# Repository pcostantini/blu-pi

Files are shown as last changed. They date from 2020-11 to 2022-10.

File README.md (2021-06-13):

# BLU-PI CYCLING COMPUTER

GPS Cycling Computer |  Raspberry Pi + GPS + ATTiny Odometer | Node.JS

| Overview | Intervals | Sys. Averages | Map | Menu | 
| --- | --- | --- | --- | ---- |
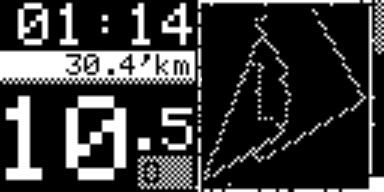
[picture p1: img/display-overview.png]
Overview Display
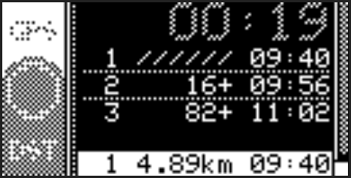
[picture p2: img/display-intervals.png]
Intervals Display
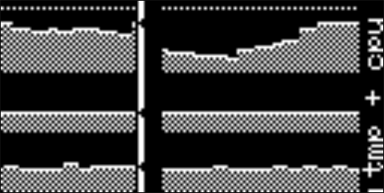
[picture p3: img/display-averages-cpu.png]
Sys. Averages Display
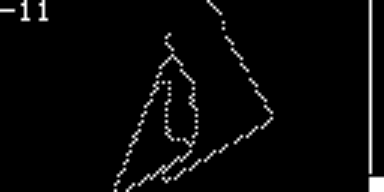
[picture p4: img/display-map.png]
Map Display
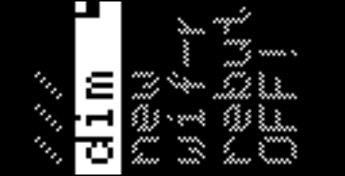
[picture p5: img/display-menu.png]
Menu Display
|  |  |  |  |  |

| Setup | Cockpit | Prototype |
| ----- | --- | --- |
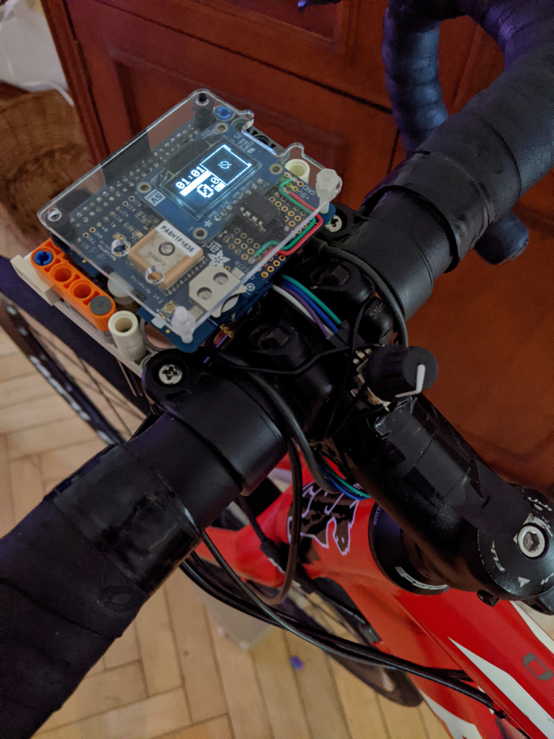
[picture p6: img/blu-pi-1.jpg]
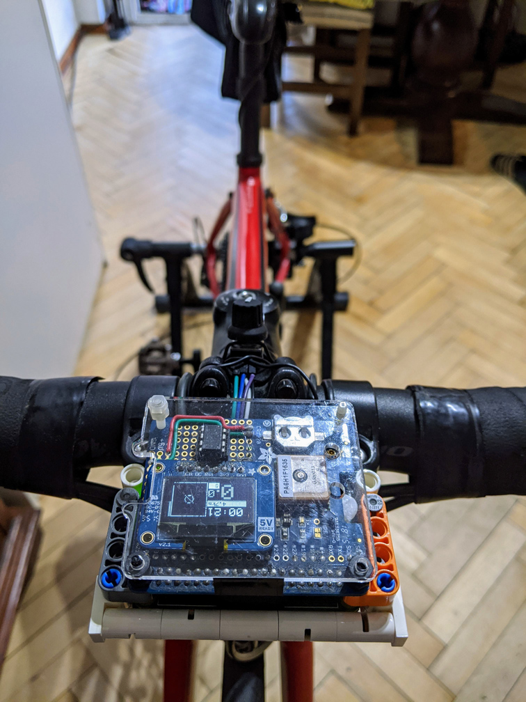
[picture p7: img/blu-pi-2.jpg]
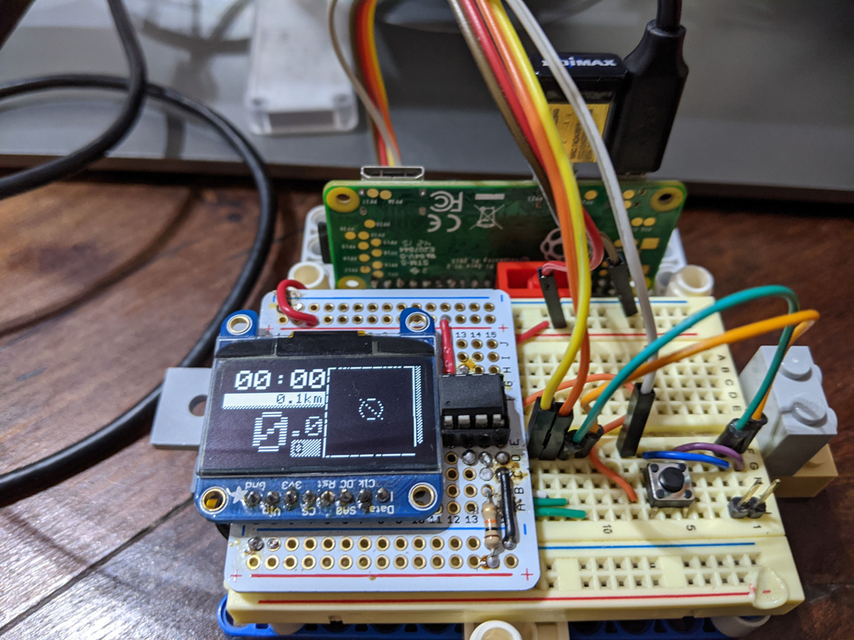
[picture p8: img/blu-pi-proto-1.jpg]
BLU-PI PROTO
|  |  |  |

## Install & Running

Install dependencies:

$ `npm i`

Running:

$ `node app`

Start on background (under screen):

$ `./start_and_watch_for_cycle.sh`

Install as service on Pi:

```sh
sudo cp blu-pi.service /etc/systemd/system/blu-pi.service
sudo systemctl enable blu-pi.service
sudo systemctl start blu-pi.service
```

## Usage

- **Rotating (the Rotary Encoder)** provides input within the current screen
- **Push button** to trigger an action within screen
- **Press Push button + rotate Encoder** to change displays:
  - **Overview**: Session elapsed time, distance, current speed and cadence.
  - **Averages**: Display Speed/Cadence and CPU/Temperature/RAM (on different scales)
  - **Intervals**: Lap times, using GPS anchor or by distance
  - **Map**: Plot of GPS points
  - **Off**: Minimal display
  - **IP**: Display device IP(s)
  - **Menu** (see [menu.js](./app/menu.js))
    - Dim display
    - New session
    - Reset wifi
    - Reset pi
    - Turn OFF

### Web Display

Open `http://[PI-IP-ADDRESS]:8080/` for a mirror of the display.

Use `ASD` keys to mimic Rotary Encoder. Long press `A` and `D` to switch screens.

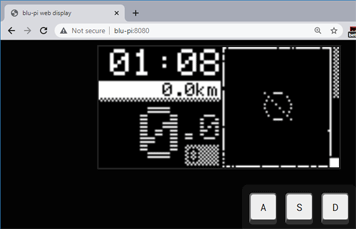
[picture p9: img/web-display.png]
Web Display


## Hardware

### Build & Wiring

- 3xGPIOs for input + 2 GNDs
  - rotary.pinA -> pi.gpio16
  - rotary.pinB -> pi.gpio26
  - rotary.push -> pi.gpio21
- using i2c (+ VI + GND)
  - oled display
    - \+ reset pin on pi.gpio4
  - attiny odometer (see [more details](./attiny_brain/READNE.md))
    - attiny.vi -> 10k resistor -> attiny.gpio3
    - attiny.ground -> reed switch -> attiny.gpio3
  - lsm303 (currently not in use - can be used to normalize GPS) ([adafruit](https://www.adafruit.com/product/1120))

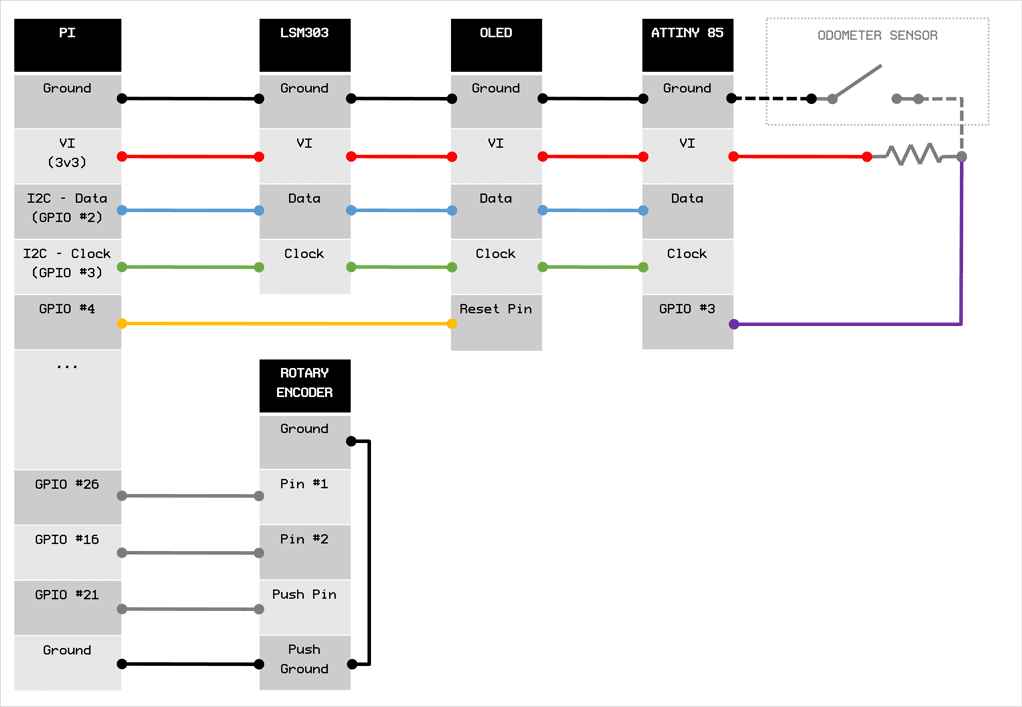
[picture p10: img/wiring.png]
Wiring

  
I2C Device Addresses:

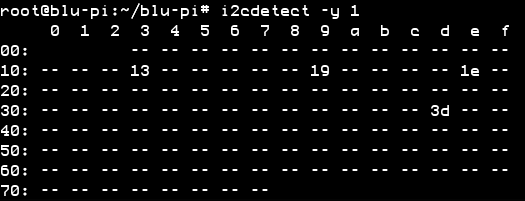
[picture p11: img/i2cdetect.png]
i2cdetect -y 1


- `0x3D`: OLED
- `0x13`: ATTiny Odometer
- `0x1E`: LSM303 Magnetometer
- `0x19`: LSM303 Accelerometer

### Parts

- pi a+ (or zero)
- wifi dongle (or zero+w)
- adafruit's gps hat ([adafruit](https://www.adafruit.com/product/2324))
  - or gps module + permaboard for wiring everything (5cm~ x 8cm~)
- oled 128x64 (configured with i2c) ([adafruit](https://www.adafruit.com/product/326))
- input: rotary encoder + push button ([adafruit](https://www.adafruit.com/product/377))
- cadence:
  - lblue(tooth) cadence or speed meter
- odometer:
  - [attiny 85](https://www.microchip.com/wwwproducts/en/ATtiny85)
  - reed switch
  - 10k resistor
- RJ45 (jack + connector) to connect the Rotary Encoder + Odometer pins to the Pi and ATTiny

## CREDITS

### Libraries

> (See [package.json](package.json) for all depedencies)

Adafruit GFX port to JavaScript ([display/adafruit-gfx](app/display/adafruit-gfx/index.js))
> https://communities.intel.com/message/237095#237095

TinyWire - ATTiny I2C library:
> https://github.com/rambo/TinyWire/tree/master

Distance (using GPS):
> https://github.com/Maciek416/gps-distance

GPX parsing:
> https://www.npmjs.com/package/gpx-parse

BLE Sensor reading (sources):
> https://github.com/amcolash/BikeVR/blob/master/public/js/bluetooth.js
> https://github.com/amcolash/oled-bike-computer/blob/master/bluetooth.js
> https://github.com/kdevware-andre/kdevware-andre.github.io/blob/master/bluetooth.js

### References

ATTiny Flashing:
> https://www.instructables.com/id/Programming-the-ATtiny85-from-Raspberry-Pi/

Map lat/long to pixel:
> http://stackoverflow.com/questions/8898120/conversion-of-lat-lng-coordinates-to-pixels-on-a-given-map-with-javascript

Kalman filter:
> https://wouterbulten.nl/blog/tech/lightweight-javascript-library-for-noise-filtering/
> https://hackaday.com/2019/05/14/the-kalman-filter-exposed/

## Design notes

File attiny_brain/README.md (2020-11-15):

# ATTINY85 ODOMETER

## Burner (using PI Hardware)

Follow instrutions from:

> https://www.instructables.com/id/Programming-the-ATtiny85-from-Raspberry-Pi/

## Pre-requisites

- Install **avrdude**: `sudo apt install avrdude`

- Install **arduino-cli**:

  > https://arduino.github.io/arduino-cli/latest/installation/

- Install Arduino Cores:

  ```bash
  arduino-cli core update-index --additional-urls https://raw.githubusercontent.com/damellis/attiny/ide-1.6.x-boards-manager/package_damellis_attiny_index.json
  arduino-cli core install arduino:avr
  arduino-cli core install attiny:avr
  ```

- Install TinyWireS lib:

  ```bash
  unzip TinyWireS.zip -d TinyWireS
  mkdir -p ~/Arduino/libraries
  mv TinyWireS ~/Arduino/libraries/
  ```

- Build and Burn:

  ```bash
  ./compile.sh
  ./burn.sh
  ```

## Sources

- Arduino IDE ATTINY Board definitions:

  https://raw.githubusercontent.com/damellis/attiny/ide-1.6.x-boards-manager/package_damellis_attiny_index.json

- TinyWireS lib:

  https://github.com/rambo/TinyWire/tree/master/TinyWireS (TinyWireS.zip was cloned from this repo)

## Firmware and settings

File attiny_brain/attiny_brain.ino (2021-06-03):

#include <TinyWireS.h>
#include <math.h>

// Config
#define SWITCH 3 // 4-Triket 3-ATTiny85
#define LED 4 // 1-Trinket 4-ATTiny85

// README
// read speed, report current speed to i2c
// api: using i2c you can request the distance, and start time

float wheelRadius = 0.33995; // 700cc x 28mm
float wheelCirc = 0;
int revolutionTimeout = 1500;

// LED Pulse
int brightness = 0; // how bright the LED is
int fadeAmount = 12; // how many points to fade the LED by
unsigned long lastFadeUpdate = 0;

// I2C Setup
#define I2C_SLAVE_ADDRESS 0x13
#ifndef TWI_RX_BUFFER_SIZE
#define TWI_RX_BUFFER_SIZE (16)
#endif

// Speed!
int speed;
float distance;
volatile byte rotation;
float timetaken, rpm, dtime;
unsigned long pevtime;

// Data to transfer
// We are reading byte to byte, so we need a way to mark the end/start of each "byte stream"
volatile uint8_t i2c_regs[] =
    {
        0x00, // speed low byte
        0x00, // speed high byte
        0x00, // distance low byte
        0x00, // distance high byte
        0x11, // this two mark the end
        0x22};
volatile byte reg_position;
const byte reg_size = sizeof(i2c_regs);

void requestEvent()
{
  TinyWireS.send(i2c_regs[reg_position]);
  // Increment the reg position on each read, and loop back to zero
  reg_position++;
  if (reg_position >= reg_size)
  {
    reg_position = 0;
  }
}

void setup()
{
  TinyWireS.begin(I2C_SLAVE_ADDRESS);
  TinyWireS.onRequest(requestEvent);

  // initialize the LED pin as an output.
  pinMode(LED, OUTPUT);
  // initialize the SWITCH pin as an input.
  pinMode(SWITCH, INPUT);
  // ...with a pullup
  digitalWrite(SWITCH, HIGH);

  wheelCirc = 2 * PI * wheelRadius;

  speed = 0;
  rotation = 0;
  rpm = 0;
  pevtime = 0;
  distance = 0;
}

// Check wheel rotation with debounce
long lastDebounceTime = 0; // the last time the output pin was toggled
long debounceDelay = 15;   // the debounce time; increase if the output flickers
int state = LOW;
bool ping(unsigned long currentMillis)
{
  //filter out any noise by setting a time buffer
  if ((currentMillis - lastDebounceTime) > debounceDelay)
  {
    bool newState = !digitalRead(SWITCH);
    bool ping = (state != newState && newState == HIGH);
    state = newState;
    if (ping)
      lastDebounceTime = currentMillis;
    return ping;
  }

  return false;
}

void loop()
{

  TinyWireS_stop_check();

  unsigned long currentMillis = millis();

  if (ping(currentMillis))
  {
    brightness = 255;
    analogWrite(LED, brightness);

    rotation++;
    distance += wheelCirc;

    int distanceInt = round(distance);

    i2c_regs[2] = lowByte(distanceInt);
    i2c_regs[3] = highByte(distanceInt);

    dtime = currentMillis;
    if (rotation >= 2)
    {
      // calc rpm
      timetaken = currentMillis - pevtime; //time in millisec
      rpm = (1000 / timetaken) * 60;
      pevtime = currentMillis;
      rotation = 0;

      // calc speed
      speed = round((wheelCirc * rpm * 3600) / 1000);
      i2c_regs[0] = lowByte(speed);
      i2c_regs[1] = highByte(speed);
    }
  }

  // drop to zero if no revolutions were detected after a while
  if (currentMillis - dtime > revolutionTimeout)
  {
    // reset
    rpm = 0;
    speed = 0;
    dtime = currentMillis;
    i2c_regs[0] = 0;
    i2c_regs[1] = 0;
  }

  // LED Pulse
  // int pulse = min(100 / 24 * speed, 255);
  // analogWrite(LED, pulse);
  if (currentMillis - lastFadeUpdate > 5)
  {

    if (brightness > 0)
    {
      // reduce pulse
      brightness = brightness - fadeAmount;
      if (brightness < 0) brightness = 0;
    }

    analogWrite(LED, brightness);
    lastFadeUpdate = currentMillis;
  }
}

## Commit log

2015-12-04 # basid read from reed switch
2015-12-18 # lsm303, pressure and temperature sensors # fixes & refactoring
2015-12-22 # proper lsm303 & bmp085 registration + npm shrinkwrap to fix i2c dep
2015-12-29 # sensors bootstrapping - added basic ticking # merged sensors data into snapshot with sensorName as properties # refactor main.js # REPL support
2015-12-29 # gpio input - added respondOnValue to limit events to open or closed circuit
2016-02-06 # change store from snapshot based to event based # refactor and sensors interval tuneup # new display code [WIP]
2016-02-06 # safe sensors creation (continue on init error)
2016-02-13 # free memory sensor - smaller, faster
2016-02-25 # basic expose of sensor data through web api
2016-02-26 # sensors updated
2016-03-04 # extract GPX file from session (sqlite db)
    - track and temperature are supported
2016-03-05 \# export/persist with sessionName - eg: 'node --harmony tools/extract-gpx.js sensors-????.sqlite3 TESTRIDE'
2016-03-10 # replay sensors wip
2016-03-10 # fix sensor event obj
2016-03-11 # refactor Display Driver - WIP # replace underscore with lodash
2016-03-12 # oled driver display
2016-04-08 # console input or hardware input
    Use --console or -c for switching to console input
2016-04-10 # gps noise filter for distance calculation
2016-04-14 # oled reset included in driver code
2016-04-16 # change persitence into continuos mode (no more sessions, just current.sqlite3)
    # merge data tools no longer required
2016-04-21 Revert "# "grid" filter for display"
    This reverts commit e0aa7da60afc5833b7b686e42d67babd84f48228.
2016-04-26 # replay using current Cpu
2016-04-27 # "grid" filter for display
2016-04-28 # plotpath, use oled driver
2016-05-05 # remove "grid filter"
2016-05-12 # driver reference on BaseDisplay
2016-05-19 # replay sensors, replace cpu and clock fixes
2016-05-19 # state refactor to include stateStore
    # allows getting current state on demand
    # instant render when changing views
    # simplified display code, only subscribe to latest events of interest
2016-05-19 # reverted sample activity
2016-05-19 # kill led lights
2016-06-20 # basic menu display # inputs change: A=NextScreen, S=CycleOptionCurrentScreen, D=CurrentScreenAccept
2016-06-23 # Merged Display and Input drivers
2016-06-23 # Replay (demo mode) using only GPS track
2016-06-24 # insert fix
2016-06-26 # resume session - basic wiring
2016-08-03 noise filter preFlush event map follow
    screensaver tweaks + noisy filter
    map + noisy filter
2017-01-05 # Display Filters refactor + Dotted Filter
2017-02-07 # hw schematics 1
    [cockpit-display-gpioattiny.fzz, cockpit-display-i2c.fzz]
2017-02-10 # Cockpit display schematic
    [cockpit-display-gpioattiny-v2.fzz]
2017-05-24 # hardware wip
    [blu-pi-display.fzz, cockpit-display-gpioattiny.fzz, cockpit-display-i2c.fzz]
2017-05-26 # protocard display
    [blu-pi-display.fzz]
2017-06-09 # Completed VI line for inputs
    [blu-pi-display.fzz]
2017-09-10 simulate input buttons on web display
2017-09-24 # attiny arduino sandbox
2017-09-28 # i2c report proto
2017-10-18 # attiny85 brain - speed sensor and odometer
2018-03-22 # digital barometer temperature reading - off!
2018-10-31 # safe init for oled display driver
2019-01-08 # update to Node v10 and i2c to raspi-i2c & i2c-bux
2020-11-08 # enable attiny speed sensor
2020-11-14 BLE sensor config (cadence only)
2020-11-14 # attiny odometer - build instructions with arduino-cli
2020-11-15 # map filter fix
2020-11-21 # rotary encoder input
2020-11-21 # update menu inputs to accommodate rotary encoder
2020-12-13 Landscape display (#8)
    * # landscape display orientation
    * # landscape display orientation tweaks
    * # print velocity from either gps or odometer
    * # drop oled reset on pin 24
    * # fix oled reset on pin 24
    * # oled reset on pins 4 (dev-board) and 24 (prototype)
    * # handle 3 digits cadence (replace hundres with glyph)
    * # general fixes
2020-12-13 # new session - cycle current.sqlite3
2021-03-01 # add averages sample to state log
2021-06-01 # print `IntervalsCount` on state preview
2021-06-02 # intervals fixes:
    - refactored clear
    - refactored current interval time using last lap anchor
2021-06-03 # attiny odometer build script fixes
    [attiny_brain.ino]
2021-06-05 # use current timestamp as default session name
2021-06-05 # restore oled driver and rotary input
2021-06-13 # readme updates (#12)
    * # readme updates
    * # hw with i2c devices
    * # display screenshots
    * # web display
    * # cleanup
    * # pics
    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
2021-12-08 # add mask filter
